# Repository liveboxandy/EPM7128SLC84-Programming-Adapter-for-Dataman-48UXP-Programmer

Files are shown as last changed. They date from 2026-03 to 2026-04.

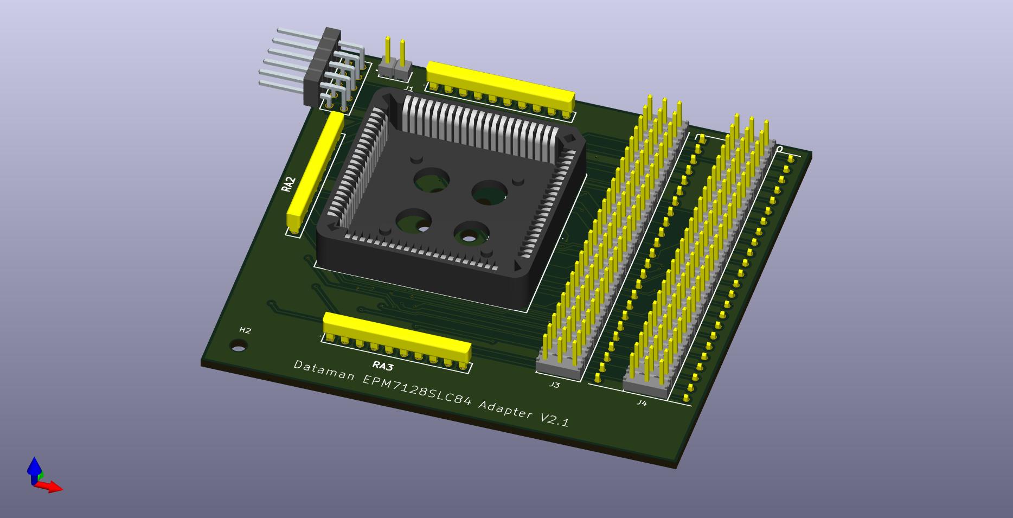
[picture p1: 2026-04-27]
EPM7128 Adapter.jpg

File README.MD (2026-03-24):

This adapter allows a Dataman UXP48 parallel programmer to program Altera EPM7128SLC84 devices that have been JTAG locked. 

The pinout has been taken from the Dataman documentation and I see no reason why it shouldn't work on any EPM7128 PLCC84 devices as they all use the same adapter SDP-7128-84 according to the documentation. 

Note that the Dataman XP and XP48 will only do 5V devices while the 48LV and 48UXP will do 3V3 devices as well

Note that the pinout is unique to the EPM7128 Series. The EPM7032, EPM7064 and EPM7160 all have their own uniquely wired adapters.

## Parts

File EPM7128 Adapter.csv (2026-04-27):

Source: | E:\Kicad\EPM7128\EPM7128 Adapter.kicad_sch
Date: | 2026-04-13T09:42:42+0100
Tool: | Eeschema 9.0.8
Generator: | C:\Program Files\KiCad\7.0\bin\scripting\plugins/bom_csv_grouped_by_value_with_fp.py
Component Count: | 21
Ref | Qnty | Value | Cmp name | Footprint | Description | Vendor | DNP
C1, C2, C3, C4, C5, C6, C7, C8 | 8 | 100nF | C | Mod:C1206 | Unpolarized capacitor
DATAMAN0 | 1 | Pin-Pin Headers 1x24 | DIL48 | Mod:DIL48 | IC Socket: 24+24 Pos Receptacle DIL Straight THT
J1 | 1 | Conn_01x02 | TSW-102-07-G-S | Mod:SAMTEC_TSW-102-07-G-S
J2 | 1 | Conn_02x05_Odd_Even | TSW-105-07-L-D | Mod:SAMTEC_TSW-105-07-L-D
J3, J4 | 2 | TSW-124-08-T-T | TSW-124-08-T-T | Mod:SAMTEC_TSW-124-08-T-T
PLCC84 | 1 | ~ | EPM7128SLC84-10 | Mod:PLCC84AT
RA1, RA2, RA3 | 3 | 10k | R_Network09_US | Mod:4610M101103LF | 9 resistor network, star topology, bussed resistors, small US symbol
UNK_HOLE_0, UNK_HOLE_1, UNK_HOLE_2, UNK_HOLE_3 | 4 | Extraction Hole | MountingHole | MountingHole:MountingHole_2.7mm_M2.5 | Mounting Hole without connection

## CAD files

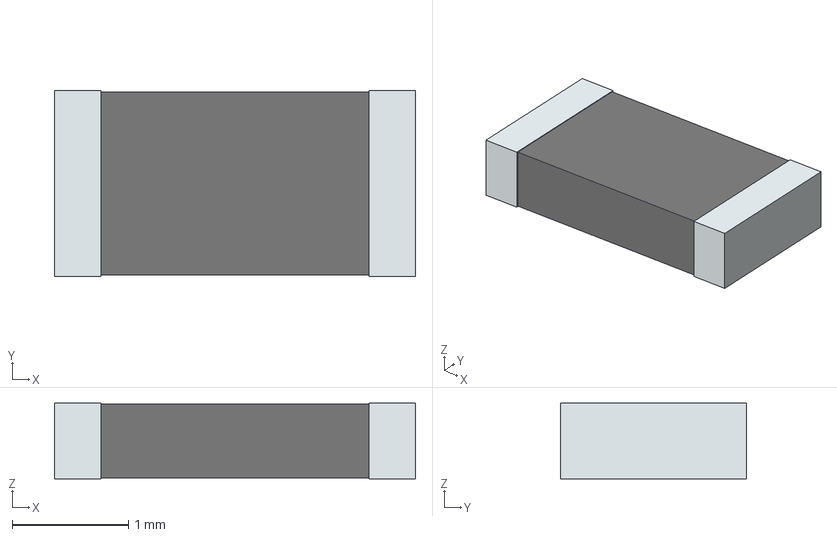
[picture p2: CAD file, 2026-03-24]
STP/RP1206BRD0710KL.stp
3.10 x 1.60 x 0.65 mm
term1
term2

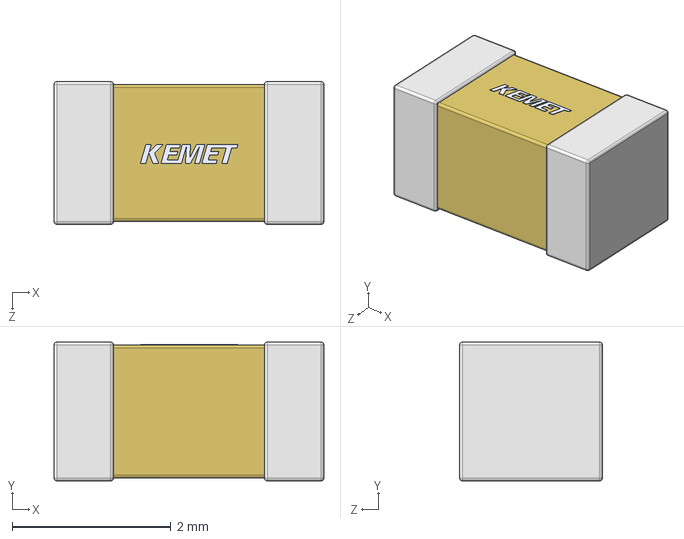
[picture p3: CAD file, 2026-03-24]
STP/C1206H104J3GACT250.stp
3.40 x 1.75 x 1.80 mm

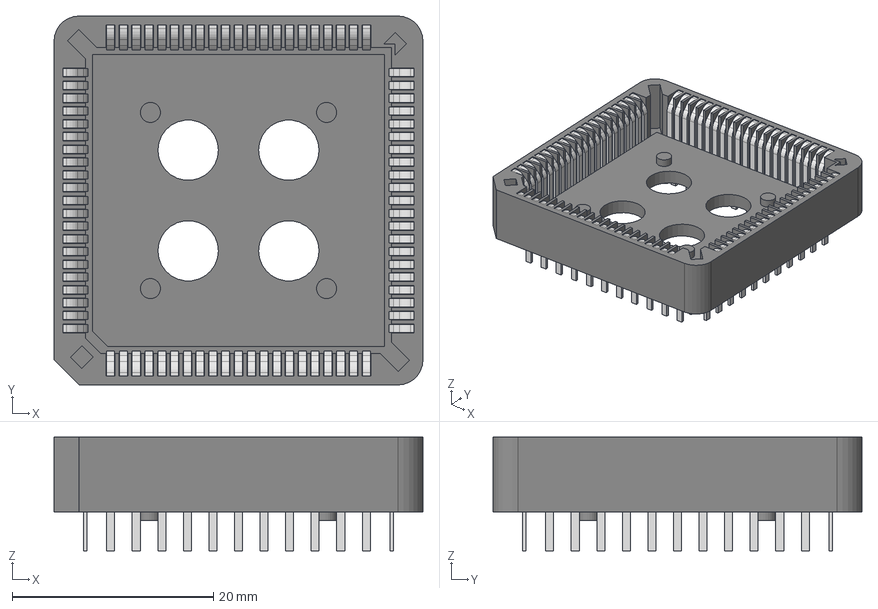
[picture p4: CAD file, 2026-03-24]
STP/PLCC-84-AT.stp
36.7 x 36.7 x 11.3 mm

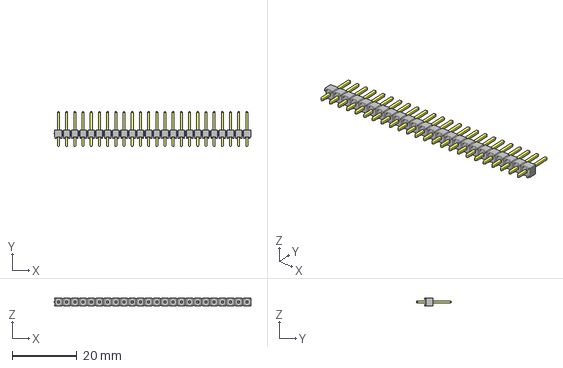
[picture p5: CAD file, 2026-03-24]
STP/TSW-124-07-L-S.stp
61.1 x 10.9 x 2.54 mm
TSW-124-07-L-S_body
T-1S6-07-TSW-1-07-24-S

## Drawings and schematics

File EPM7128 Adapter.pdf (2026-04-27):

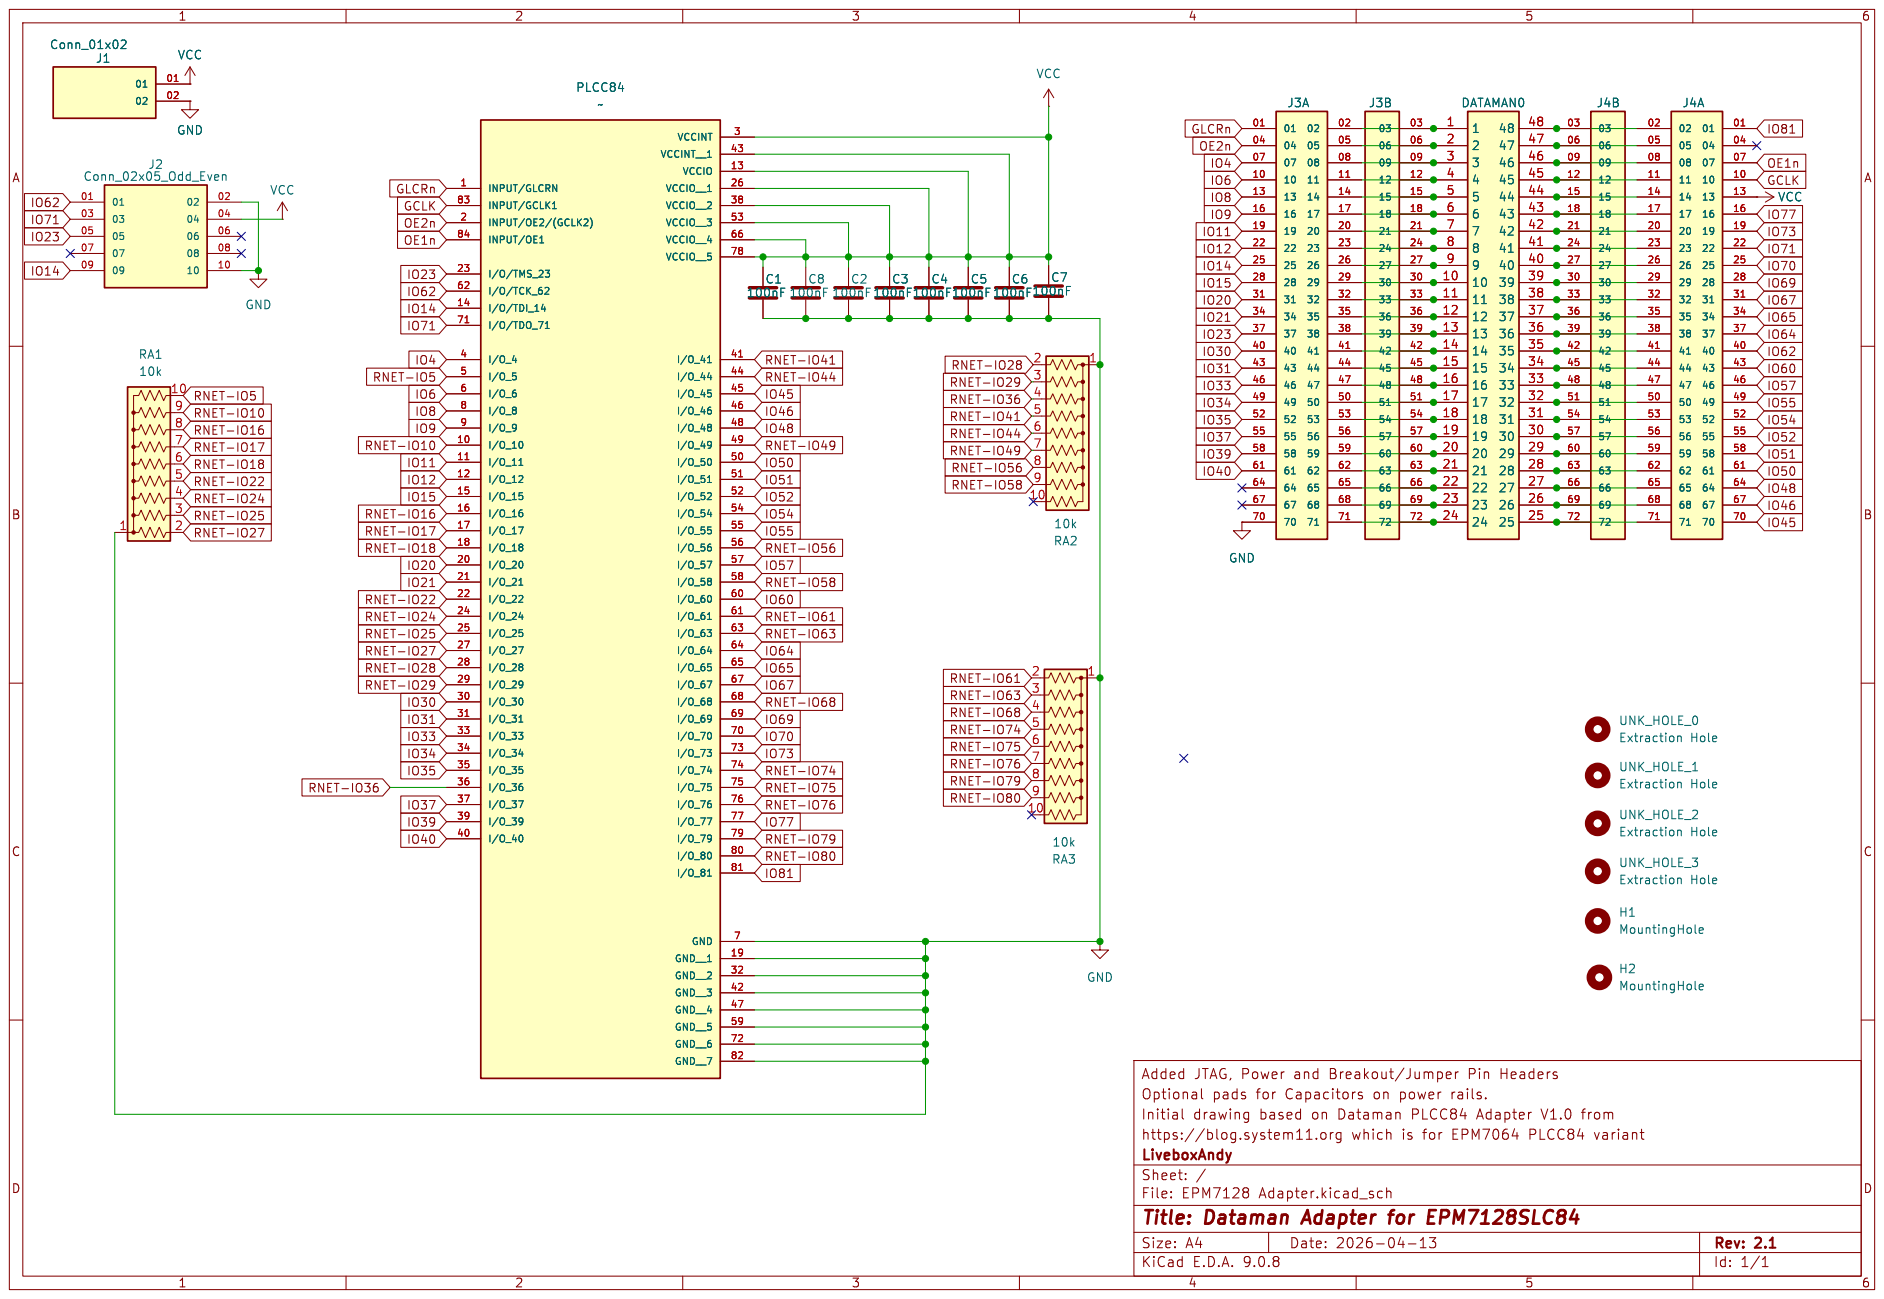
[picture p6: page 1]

IO45 RNET-IO63 RNET-IO80 RNET-IO61 RNET-IO79 RNET-IO76 RNET-IO75 OE2n

IO71 RNET-IO28 RNET-IO29 RNET-IO36 RNET-IO41

File: EPM7128 Adapter.kicad_sch Sheet: / LiveboxAndy

Id: 1/1 Title: Dataman Adapter for EPM7128SLC84

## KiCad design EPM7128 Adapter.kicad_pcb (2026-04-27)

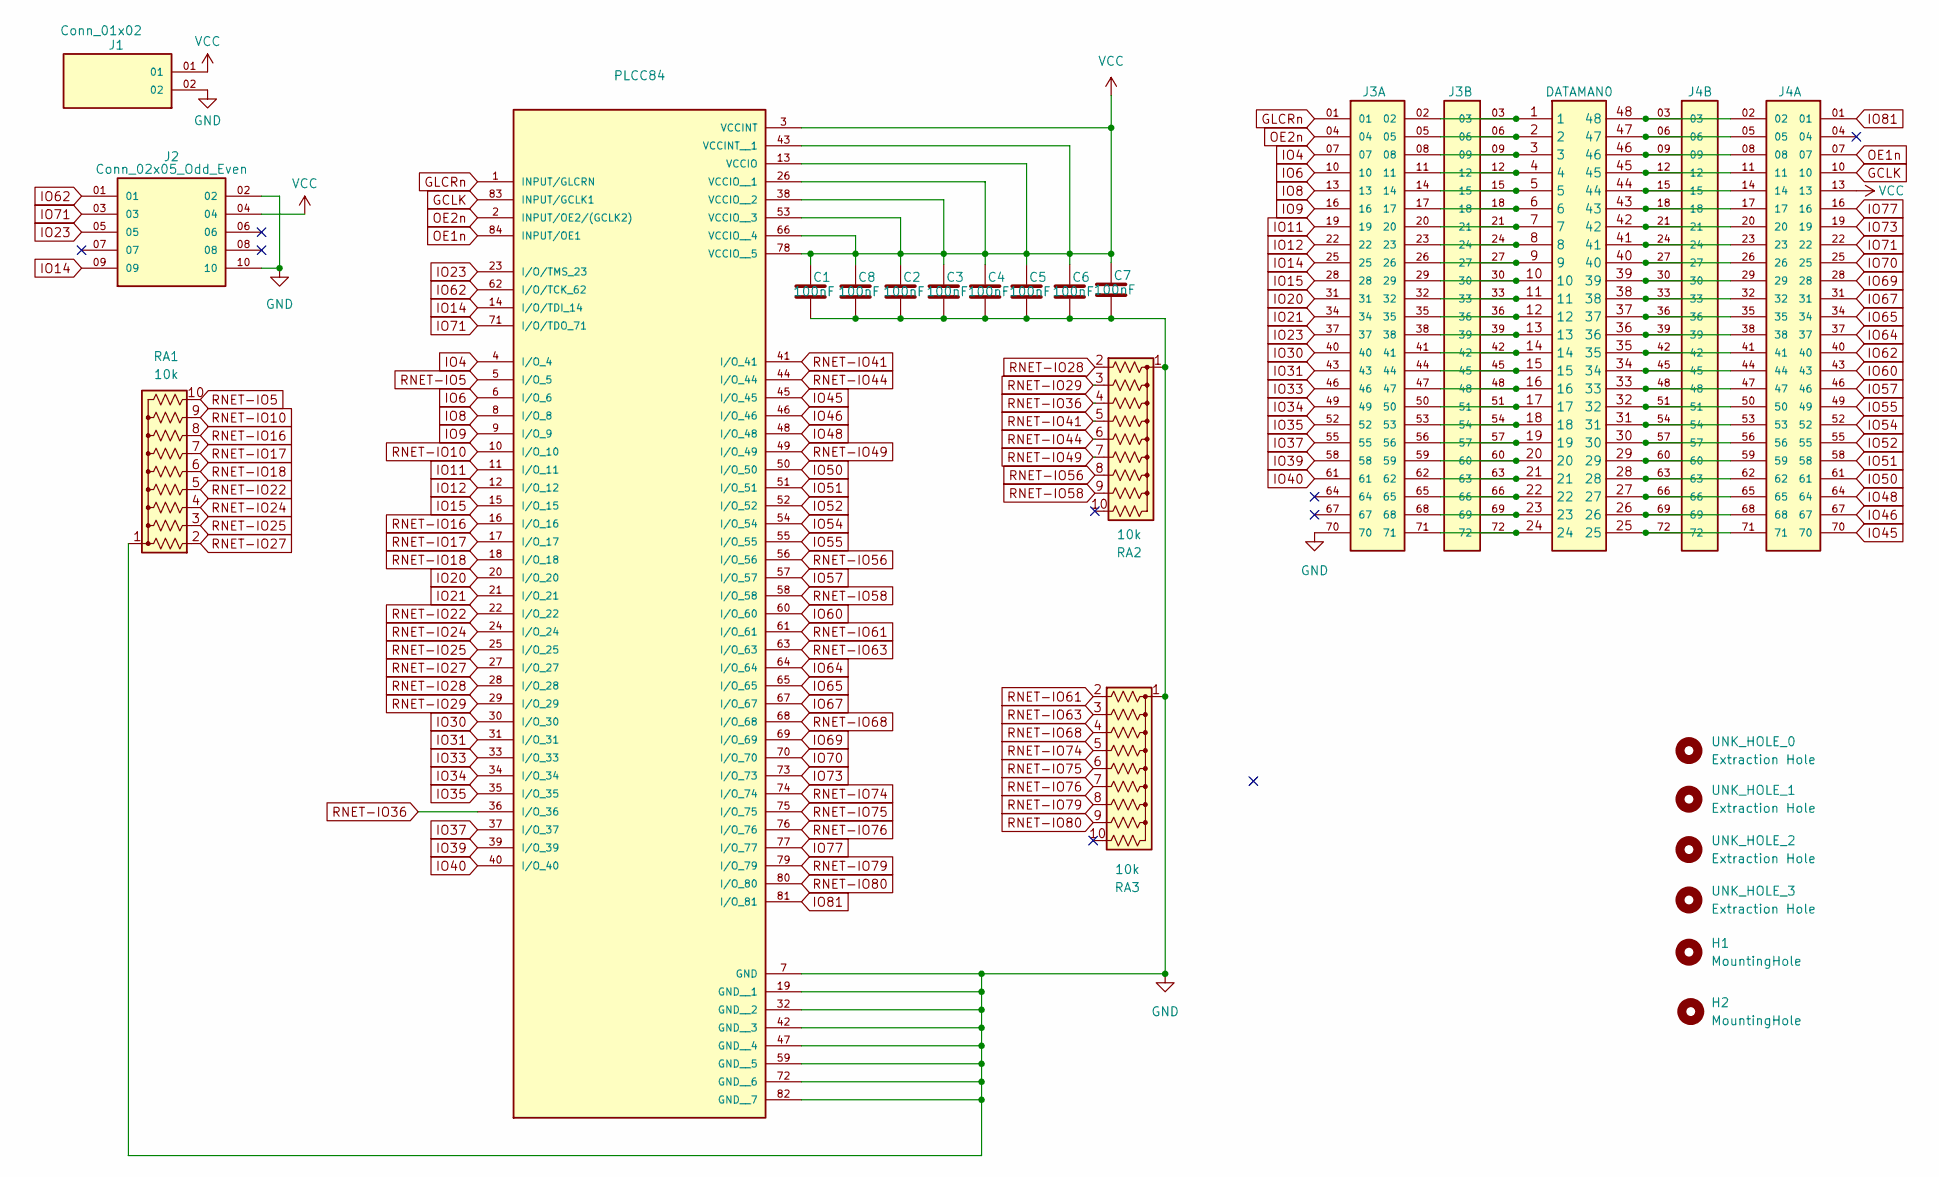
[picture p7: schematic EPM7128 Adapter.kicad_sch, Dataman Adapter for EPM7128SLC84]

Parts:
C1, C2, C3, C4, C5, C6, C7, C8: 100nF; C1206
DATAMAN0: Pin-Pin Headers 1x24; DIL48
H1, H2: MountingHole; MountingHole_2.7mm_M2.5
J1: Conn_01x02; SAMTEC_TSW-102-07-G-S; PARTREV R
J2: Conn_02x05_Odd_Even; SAMTEC_TSW-105-07-L-D; PARTREV R; DigiKey_Part_Number SAM1030-05-ND
J3, J4: TSW-124-08-T-T; SAMTEC_TSW-124-08-T-T; PARTREV R
PLCC84: PLCC84AT
RA1, RA2, RA3: 10k; 4610M101103LF
UNK_HOLE_0, UNK_HOLE_1, UNK_HOLE_2, UNK_HOLE_3: Extraction Hole; MountingHole_2.7mm_M2.5

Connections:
GCLK: J4.10, PLCC84.83 (INPUT/GCLK1)
GLCRn: J3.01, PLCC84.1 (INPUT/GLCRN)
GND: C1.2, C2.2, C3.2, C4.2, C5.2, C6.2, C7.2, C8.2, J1.02, J2.02, J2.10, J3.70, PLCC84.7 (GND), PLCC84.19 (GND__1), PLCC84.32 (GND__2), PLCC84.42 (GND__3), PLCC84.47 (GND__4), PLCC84.59 (GND__5), PLCC84.72 (GND__6), PLCC84.82 (GND__7), RA1.1 (common), RA2.1 (common), RA3.1 (common)
IO4: J3.07, PLCC84.4 (I/O_4)
IO6: J3.10, PLCC84.6 (I/O_6)
IO8: J3.13, PLCC84.8 (I/O_8)
IO9: J3.16, PLCC84.9 (I/O_9)
IO11: J3.19, PLCC84.11 (I/O_11)
IO12: J3.22, PLCC84.12 (I/O_12)
IO14: J2.09, J3.25, PLCC84.14 (I/O/TDI_14)
IO15: J3.28, PLCC84.15 (I/O_15)
IO20: J3.31, PLCC84.20 (I/O_20)
IO21: J3.34, PLCC84.21 (I/O_21)
IO23: J2.05, J3.37, PLCC84.23 (I/O/TMS_23)
IO30: J3.40, PLCC84.30 (I/O_30)
IO31: J3.43, PLCC84.31 (I/O_31)
IO33: J3.46, PLCC84.33 (I/O_33)
IO34: J3.49, PLCC84.34 (I/O_34)
IO35: J3.52, PLCC84.35 (I/O_35)
IO37: J3.55, PLCC84.37 (I/O_37)
IO39: J3.58, PLCC84.39 (I/O_39)
IO40: J3.61, PLCC84.40 (I/O_40)
IO45: J4.70, PLCC84.45 (I/O_45)
IO46: J4.67, PLCC84.46 (I/O_46)
IO48: J4.64, PLCC84.48 (I/O_48)
IO50: J4.61, PLCC84.50 (I/O_50)
IO51: J4.58, PLCC84.51 (I/O_51)
IO52: J4.55, PLCC84.52 (I/O_52)
IO54: J4.52, PLCC84.54 (I/O_54)
IO55: J4.49, PLCC84.55 (I/O_55)
IO57: J4.46, PLCC84.57 (I/O_57)
IO60: J4.43, PLCC84.60 (I/O_60)
IO62: J2.01, J4.40, PLCC84.62 (I/O/TCK_62)
IO64: J4.37, PLCC84.64 (I/O_64)
IO65: J4.34, PLCC84.65 (I/O_65)
IO67: J4.31, PLCC84.67 (I/O_67)
IO69: J4.28, PLCC84.69 (I/O_69)
IO70: J4.25, PLCC84.70 (I/O_70)
IO71: J2.03, J4.22, PLCC84.71 (I/O/TDO_71)
IO73: J4.19, PLCC84.73 (I/O_73)
IO77: J4.16, PLCC84.77 (I/O_77)
IO81: J4.01, PLCC84.81 (I/O_81)
unnamed: DATAMAN0.1, J3.02, J3.03
unnamed: DATAMAN0.2, J3.05, J3.06
unnamed: DATAMAN0.3, J3.08, J3.09
unnamed: DATAMAN0.4, J3.11, J3.12
unnamed: DATAMAN0.5, J3.14, J3.15
unnamed: DATAMAN0.6, J3.17, J3.18
unnamed: DATAMAN0.7, J3.20, J3.21
unnamed: DATAMAN0.8, J3.23, J3.24
unnamed: DATAMAN0.9, J3.26, J3.27
unnamed: DATAMAN0.10, J3.29, J3.30
unnamed: DATAMAN0.11, J3.32, J3.33
unnamed: DATAMAN0.12, J3.35, J3.36
unnamed: DATAMAN0.13, J3.38, J3.39
unnamed: DATAMAN0.14, J3.41, J3.42
unnamed: DATAMAN0.15, J3.44, J3.45
unnamed: DATAMAN0.16, J3.47, J3.48
unnamed: DATAMAN0.17, J3.50, J3.51
unnamed: DATAMAN0.18, J3.53, J3.54
unnamed: DATAMAN0.19, J3.56, J3.57
unnamed: DATAMAN0.20, J3.59, J3.60
unnamed: DATAMAN0.21, J3.62, J3.63
unnamed: DATAMAN0.22, J3.65, J3.66
unnamed: DATAMAN0.23, J3.68, J3.69
unnamed: DATAMAN0.24, J3.71, J3.72
unnamed: DATAMAN0.25, J4.71, J4.72
unnamed: DATAMAN0.26, J4.68, J4.69
unnamed: DATAMAN0.27, J4.65, J4.66
unnamed: DATAMAN0.28, J4.62, J4.63
unnamed: DATAMAN0.29, J4.59, J4.60
unnamed: DATAMAN0.30, J4.56, J4.57
unnamed: DATAMAN0.31, J4.53, J4.54
unnamed: DATAMAN0.32, J4.50, J4.51
unnamed: DATAMAN0.33, J4.47, J4.48
unnamed: DATAMAN0.34, J4.44, J4.45
unnamed: DATAMAN0.35, J4.41, J4.42
unnamed: DATAMAN0.36, J4.38, J4.39
unnamed: DATAMAN0.37, J4.35, J4.36
unnamed: DATAMAN0.38, J4.32, J4.33
unnamed: DATAMAN0.39, J4.29, J4.30
unnamed: DATAMAN0.40, J4.26, J4.27
unnamed: DATAMAN0.41, J4.23, J4.24
unnamed: DATAMAN0.42, J4.20, J4.21
unnamed: DATAMAN0.43, J4.17, J4.18
unnamed: DATAMAN0.44, J4.14, J4.15
unnamed: DATAMAN0.45, J4.11, J4.12
unnamed: DATAMAN0.46, J4.08, J4.09
unnamed: DATAMAN0.47, J4.05, J4.06
unnamed: DATAMAN0.48, J4.02, J4.03
OE1n: J4.07, PLCC84.84 (INPUT/OE1)
OE2n: J3.04, PLCC84.2 (INPUT/OE2/(GCLK2))
RNET-IO5: PLCC84.5 (I/O_5), RA1.10 (R9)
RNET-IO10: PLCC84.10 (I/O_10), RA1.9 (R8)
RNET-IO16: PLCC84.16 (I/O_16), RA1.8 (R7)
RNET-IO17: PLCC84.17 (I/O_17), RA1.7 (R6)
RNET-IO18: PLCC84.18 (I/O_18), RA1.6 (R5)
RNET-IO22: PLCC84.22 (I/O_22), RA1.5 (R4)
RNET-IO24: PLCC84.24 (I/O_24), RA1.4 (R3)
RNET-IO25: PLCC84.25 (I/O_25), RA1.3 (R2)
RNET-IO27: PLCC84.27 (I/O_27), RA1.2 (R1)
RNET-IO28: PLCC84.28 (I/O_28), RA2.2 (R1)
RNET-IO29: PLCC84.29 (I/O_29), RA2.3 (R2)
RNET-IO36: PLCC84.36 (I/O_36), RA2.4 (R3)
RNET-IO41: PLCC84.41 (I/O_41), RA2.5 (R4)
RNET-IO44: PLCC84.44 (I/O_44), RA2.6 (R5)
RNET-IO49: PLCC84.49 (I/O_49), RA2.7 (R6)
RNET-IO56: PLCC84.56 (I/O_56), RA2.8 (R7)
RNET-IO58: PLCC84.58 (I/O_58), RA2.9 (R8)
RNET-IO61: PLCC84.61 (I/O_61), RA3.2 (R1)
RNET-IO63: PLCC84.63 (I/O_63), RA3.3 (R2)
RNET-IO68: PLCC84.68 (I/O_68), RA3.4 (R3)
RNET-IO74: PLCC84.74 (I/O_74), RA3.5 (R4)
RNET-IO75: PLCC84.75 (I/O_75), RA3.6 (R5)
RNET-IO76: PLCC84.76 (I/O_76), RA3.7 (R6)
RNET-IO79: PLCC84.79 (I/O_79), RA3.8 (R7)
RNET-IO80: PLCC84.80 (I/O_80), RA3.9 (R8)
VCC: C1.1, C2.1, C3.1, C4.1, C5.1, C6.1, C7.1, C8.1, J1.01, J2.04, J4.13, PLCC84.3 (VCCINT), PLCC84.13 (VCCIO), PLCC84.26 (VCCIO__1), PLCC84.38 (VCCIO__2), PLCC84.43 (VCCINT__1), PLCC84.53 (VCCIO__3), PLCC84.66 (VCCIO__4), PLCC84.78 (VCCIO__5)

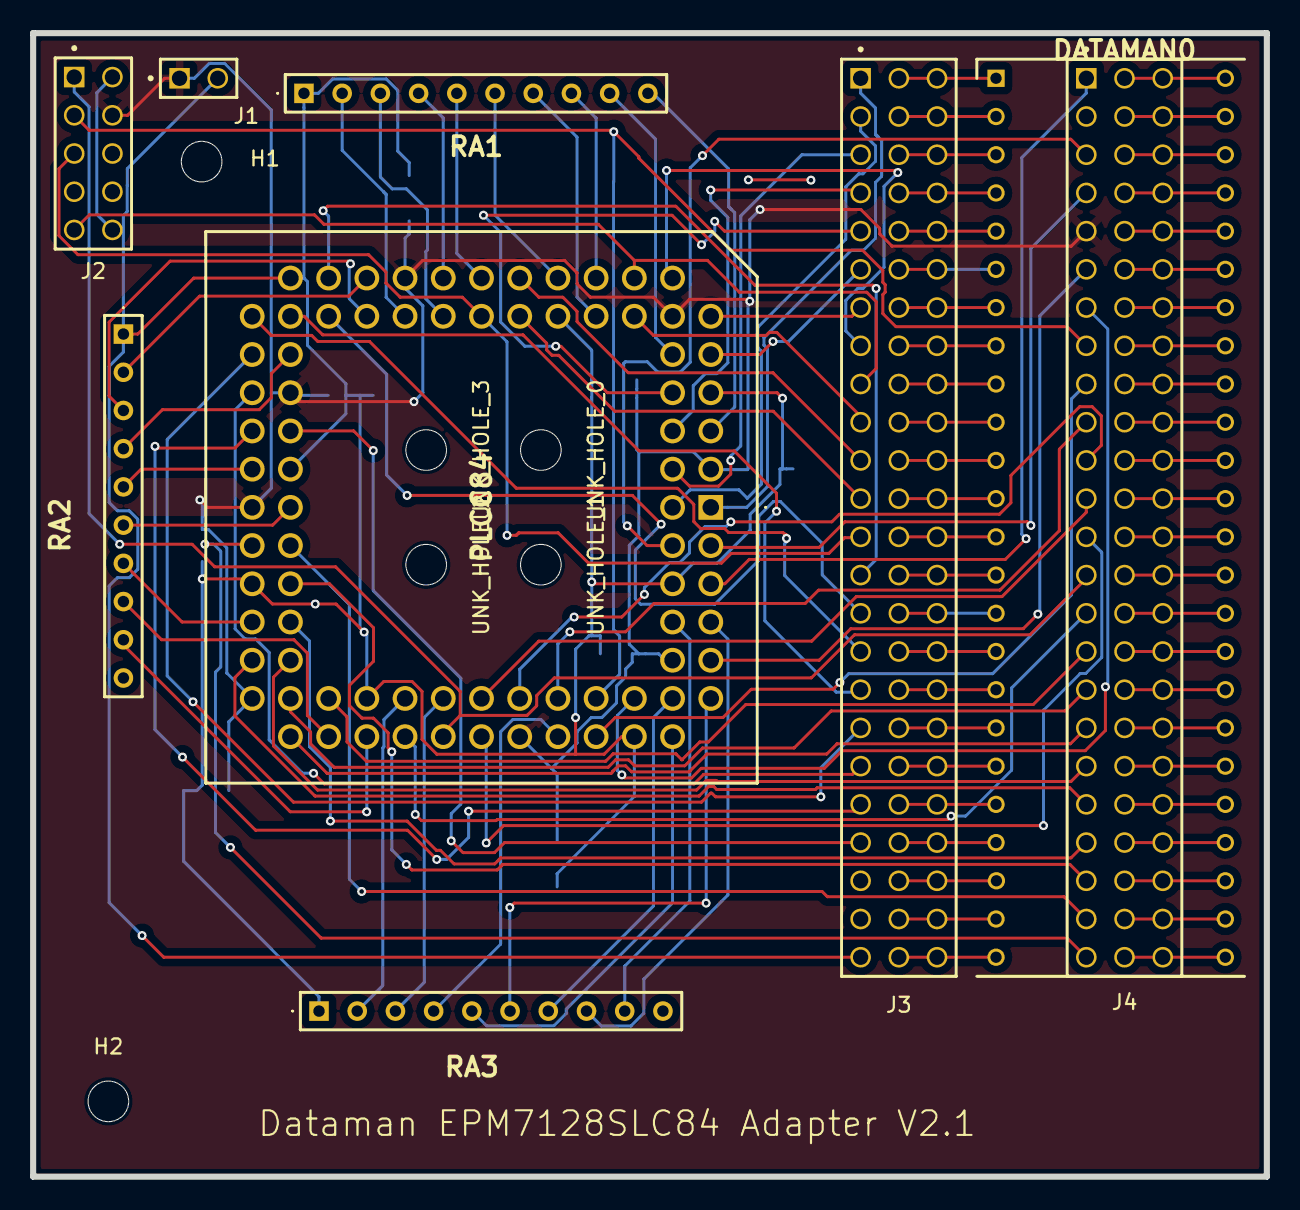
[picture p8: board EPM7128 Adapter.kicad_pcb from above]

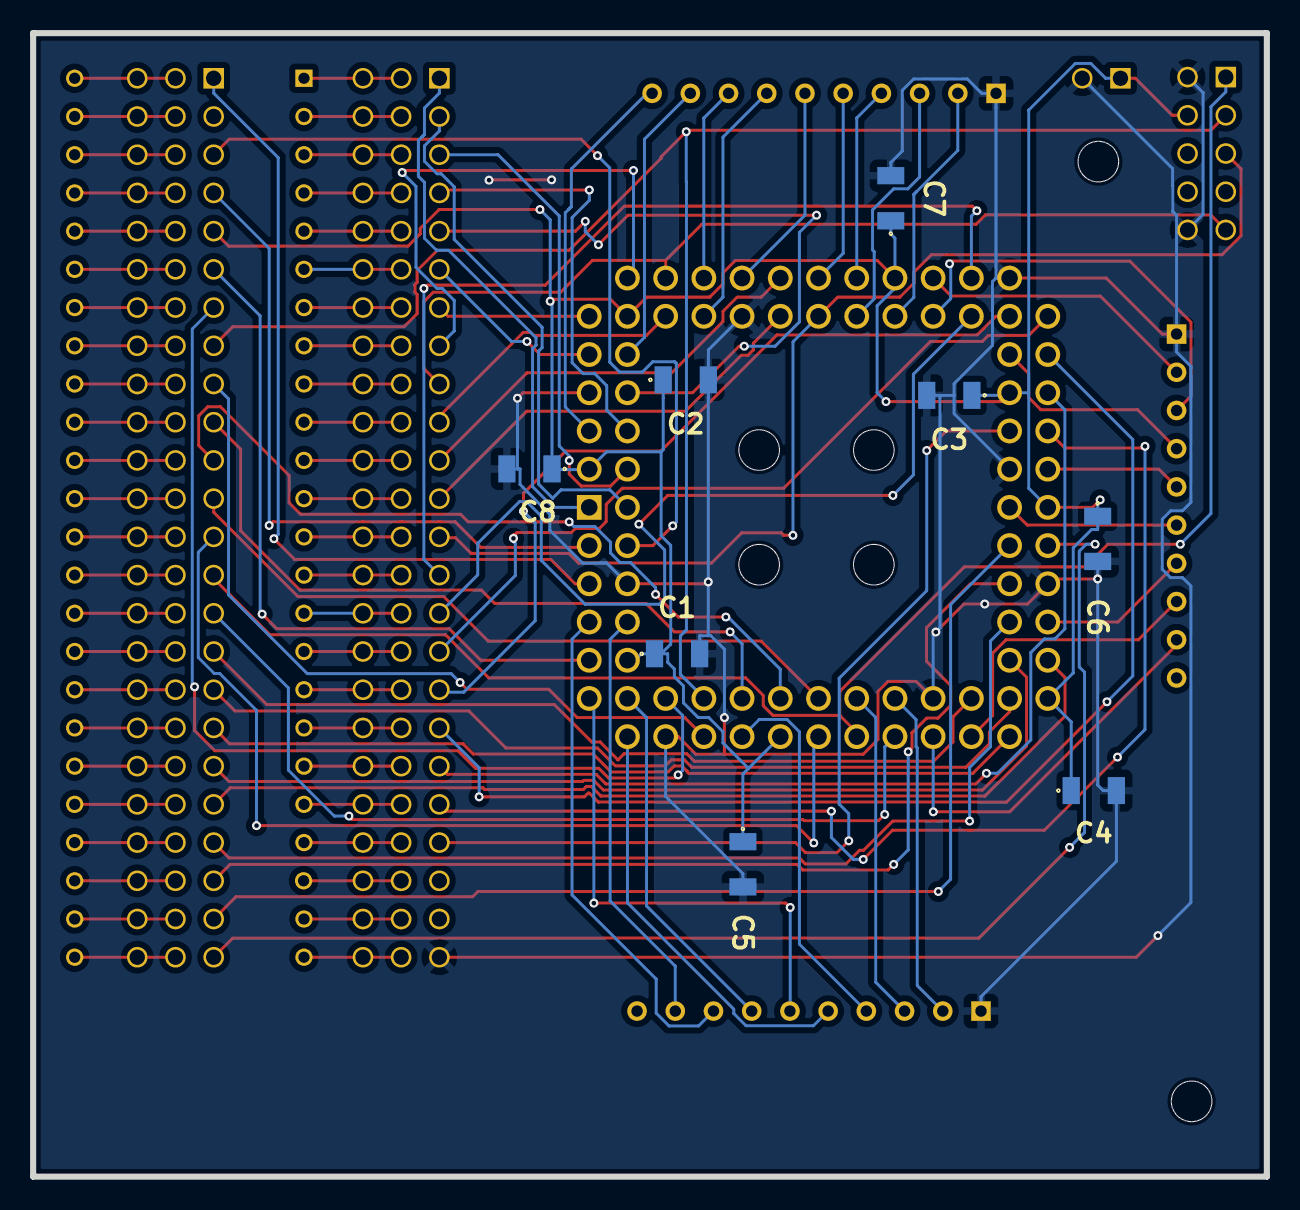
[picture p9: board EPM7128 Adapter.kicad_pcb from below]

Board: 2 copper layers, 82.0 x 76.0 mm, 23 parts (8 on the bottom side), 118 nets.

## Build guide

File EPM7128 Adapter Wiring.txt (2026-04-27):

*	CONNECTION	TABLE:	*
*********************************************************************
PIN/Signal	PLCC	DIP
	Names	SOCKET	Base
GCLRn/INPUT	01	01	
OE2n/INPUT	02	02	
	VCC	03	44	
	I/O	04	03	
	I/O	05	10K-Gnd	
	I/O	06	04	
	GND	07	24	
	I/O	08	05	
	I/O	09	06	
	I/O	10	10K-Gnd	
	I/O	11	07	
	I/O	12	08	
	VCC	13	44	
	I/O	14	09	
	I/O	15	10	
	I/O	16	10K-Gnd	
	I/O	17	10K-Gnd	
	I/O	18	10K-Gnd	
	GND	19	24	
	I/O	20	11	
	I/O	21	12	
	I/O	22	10K-Gnd	
	I/O	23	13	
	I/O	24	10K-Gnd	
	I/O	25	10K-Gnd	
	VCC	26	44	
	I/O	27	10K-Gnd	
	I/O	28	10K-Gnd	
	I/O	29	10K-Gnd	
	I/O	30	14	
	I/O	31	15	
	GND	32	24	
	I/O	33	16	
	I/O	34	17	
	I/O	35	18	
	I/O	36	10K-Gnd	
	I/O	37	19	
	VCC	38	44	
	I/O	39	20	
	I/O	40	21	
	I/O	41	10K-Gnd	
	GND	42	24	
	VCC	43	44
	I/O	44	10K-Gnd
	I/O	45	25
	I/O	46	26
	GND	47	24
	I/O	48	27
	I/O	49	10K-Gnd
	I/O	50	28
	I/O	51	29
	I/O	52	30
	VCC	53	44
	I/O	54	31
	I/O	55	32
	I/O	56	10K-Gnd
	I/O	57	33
	I/O	58	10K-Gnd
	GND	59	24
	I/O	60	34
	I/O	61	10K-Gnd
	I/O	62	35
	I/O	63	10K-Gnd
	I/O	64	36
	I/O	65	37
	VCC	66	44
	I/O	67	38
	I/O	68	10K-Gnd
	I/O	69	39
	I/O	70	40
	I/O	71	41
	GND	72	24
	I/O	73	42
	I/O	74	10K-Gnd
	I/O	75	10K-Gnd
	I/O	76	10K-Gnd
	I/O	77	43
	VCC	78	44
	I/O	79	10K-Gnd
	I/O	80	10K-Gnd
	I/O	81	48
	GND	82	24
GCLK/INPUT	83	45
OE1n/INPUT	84	46

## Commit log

2026-03-24 Initial upload of files
    [C1206H104J3GACT250.stp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]
2026-04-27 Add files via upload
    Correct issue with lack of Gnd connection to JTAG, RNETs and PLCC Socket.
    [EPM7128 Adapter.csv, EPM7128 Adapter.kicad_pcb, EPM7128 Adapter.kicad_sch]
2026-04-27 Add files via upload
    Update to correct issue with no Gnd connections to PLCC, RNETs and JTAG
    [EPM7128 Adapter-B_Courtyard.gbr, EPM7128 Adapter-B_Cu.gbr, EPM7128 Adapter-B_Fab.gbr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]

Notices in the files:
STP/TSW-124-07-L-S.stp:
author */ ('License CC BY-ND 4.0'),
